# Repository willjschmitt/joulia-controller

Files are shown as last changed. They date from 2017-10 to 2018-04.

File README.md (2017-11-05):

# joulia-controller
 

Controller for the electric brewing hardware.

## Quickstart
Install Raspbian on a fresh SD card, and boot your Raspberry Pi.

Enable SSH (optional), for installing remotely. Make sure the password for the
main account is changed to a secure password. Enable I2C and SPI.

Install Anaconda (Miniconda), using the default options (installing to
`/home/pi/miniconda`):
```
wget http://repo.continuum.io/miniconda/Miniconda3-latest-Linux-armv7l.sh
bash Miniconda3-latest-Linux-arm71.sh
```
Answer all questions posed.

Clone the source:
```git clone https://github.com/willjschmitt/joulia-controller.git```

Create a conda environment and install the dependencies:
```
cd joulia-controller
/home/pi/miniconda3/bin/conda create --name joulia-controller python=3
source /home/pi/miniconda3/bin/activate joulia-controller
pip install -r requirements.txt
```

Create a log directory for joulia and change the owner to pi:
```
sudo mkdir /var/log/joulia
sudo chown pi:pi /var/log/joulia
```

### Automatic Startup
To automatically, launch the software on startup, install the contents from
`crontab` into the root cron table using:
```
sudo crontab -e
```

In the crontab, you must update the environment variables in angle brackets per
the definitions:
 * `JOULIA_WEBSERVER_HOST` - The webserver this controller should stream data to
   (usually `joulia.io`)
 * `JOULIA_WEBSERVER_AUTHTOKEN` - The authtoken provided in your dashboard on
   joulia.io, used to authenticate the controller and identify controller
   information.

### Manual Startup
Run the controller:
```
cd joulia-controller
source /home/pi/miniconda3/bin/activate joulia-controller
export JOULIA_WEBSERVER_HOST=joulia.io
export JOULIA_WEBSERVER_AUTHTOKEN=<insert token>
python main.py
```

## Connections to Hardware
This project is meant to be run on a Raspberry Pi and makes use of the GPIO pins.

### Analog Measurement
Make sure I2C is appropriately turned on on the Raspberry Pi. Install the Arduino I2C Analog Reader software onto the Arduino, so it can communicate the temperature measurements to the Raspberry Pi.

### Digital Control
Connect the Solid State Relay input gate for the Boil Kettle to Pin 0 on the Raspberry Pi.
Connect the Solid State Relay input gate for the Main Pump to Pin 1 on the Raspberry Pi.

## Related Projects
This project is part of the series of projects for the Joulia Brewing System:
* [joulia-webserver](https://github.com/willjschmitt/joulia-webserver) - Remote webserver to log data and allow for livestreaming of data to other clients and receive commands from other clients.
* [joulia-controller](https://github.com/willjschmitt/joula-controller) - This project.
* joulia-fermentation - Planned project to control the fementation operations.

## Licensing
Copyright 2016 William Schmitt. All Rights Reserved.

The intention is to make this project open-sourced, but at this moment is maintained under personal copyright until a few things can be worked through.

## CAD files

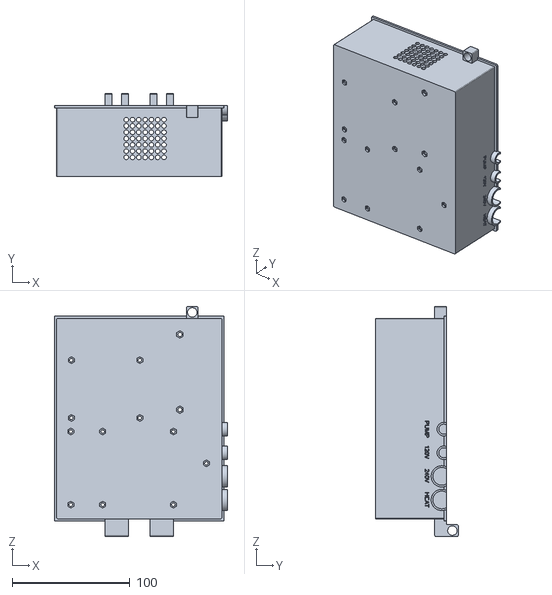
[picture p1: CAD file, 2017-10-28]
hardware/enclosure.stl
147.0 x 70.0 x 195.0

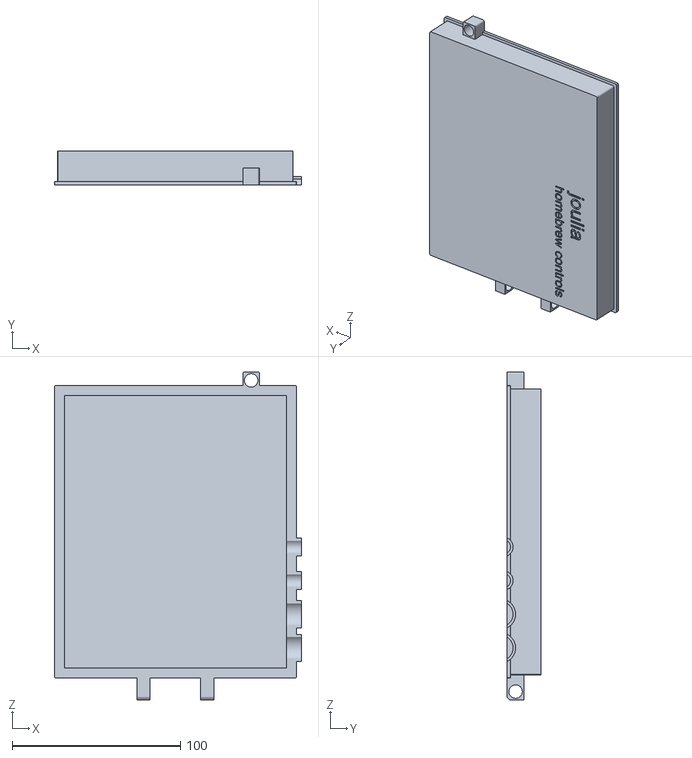
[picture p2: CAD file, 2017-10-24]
hardware/enclosure_lid.stl
147.0 x 20.0 x 195.0

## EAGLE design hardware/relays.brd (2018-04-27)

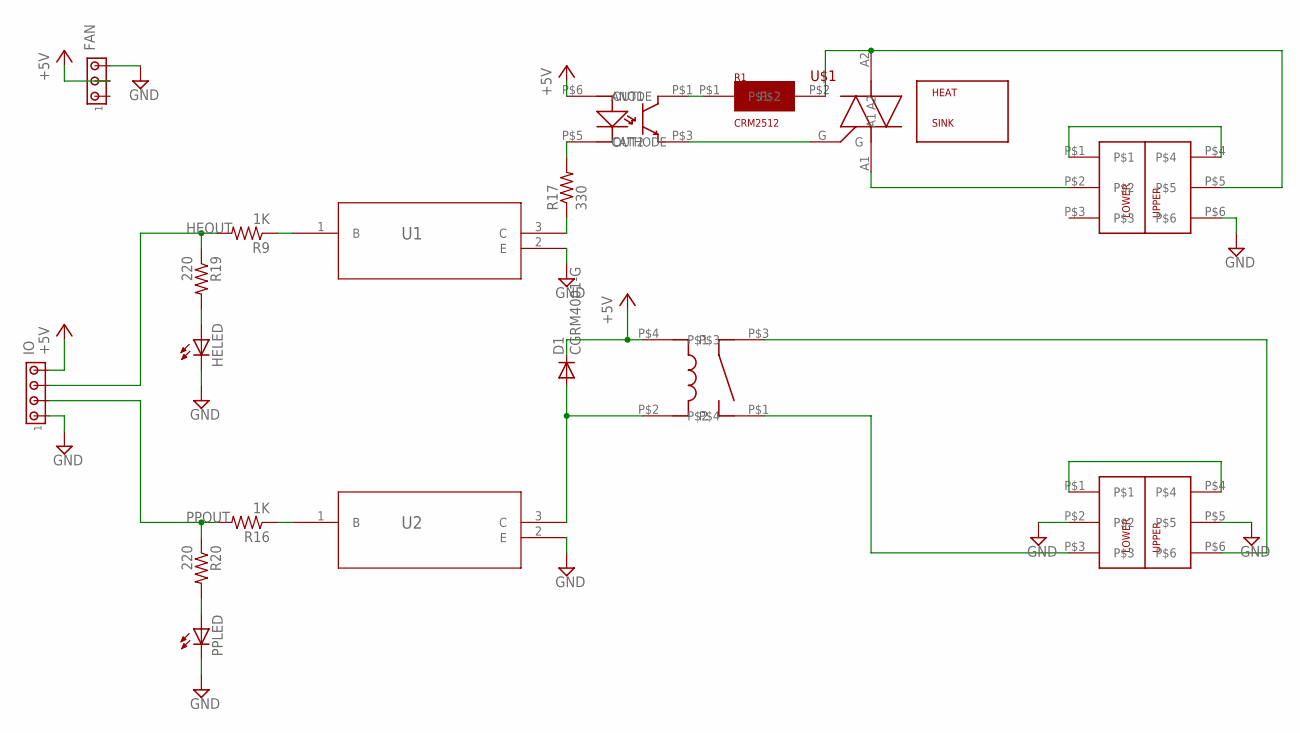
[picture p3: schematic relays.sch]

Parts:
D1: CGRM4001-G; SOD-123_MINI-SMA
FAN: MTA03-100; 10X03MTA
HELED: LED_ESML0603; LED_SML0603
IO: MTA04-100; 10X04MTA
PPLED: LED_ESML0603; LED_SML0603
R1: CRM2512; 2512(6432METRIC)
R9, R16: 1K; R0402
R17: 330; R1206
R19, R20: 220; R0402
U1, U2: MMBT2222ALT1G; SOT-23
U$1: T3050H-6I; TO-220
U$2: VM1-038-1AEHORIZONTAL; VM2-038-1AE
U$3: G5LE-1A4_DC5
U$4: PC1725041; PC-MKKDS1.5/3-5.08
U$5: MOC3020S; 6-SMD
U$6: PC1719028; PC-MKKDS5/3-9.5

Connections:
120H: U$3.P$1, U$4.P$3
120N: U$4.P$1, U$4.P$4
+5V: D1.C, FAN.2, IO.4, U$3.P$4, U$5.P$6 (ANODE)
+120: U$6.P$1, U$6.P$4
-120: U$1.A1, U$6.P$2
GND: FAN.3, HELED.C, IO.1, PPLED.C, U1.2 (E), U2.2 (E), U$4.P$2, U$4.P$5, U$6.P$6
HEOUT: IO.3, R9.2, R19.1
unnamed: R17.1, U1.3 (C)
unnamed: R17.2, U$5.P$5 (CATHODE)
unnamed: R9.1, U1.1 (B)
unnamed: R16.1, U2.1 (B)
unnamed: D1.A, U2.3 (C), U$3.P$2
unnamed: U$1.G, U$5.P$3 (OUT2)
unnamed: R1.P$1, U$5.P$1 (OUT1)
unnamed: R1.P$2, U$1.A2, U$6.P$5
unnamed: U$3.P$3, U$4.P$6
unnamed: HELED.A, R19.2
unnamed: PPLED.A, R20.2
PPOUT: IO.2, R16.2, R20.1

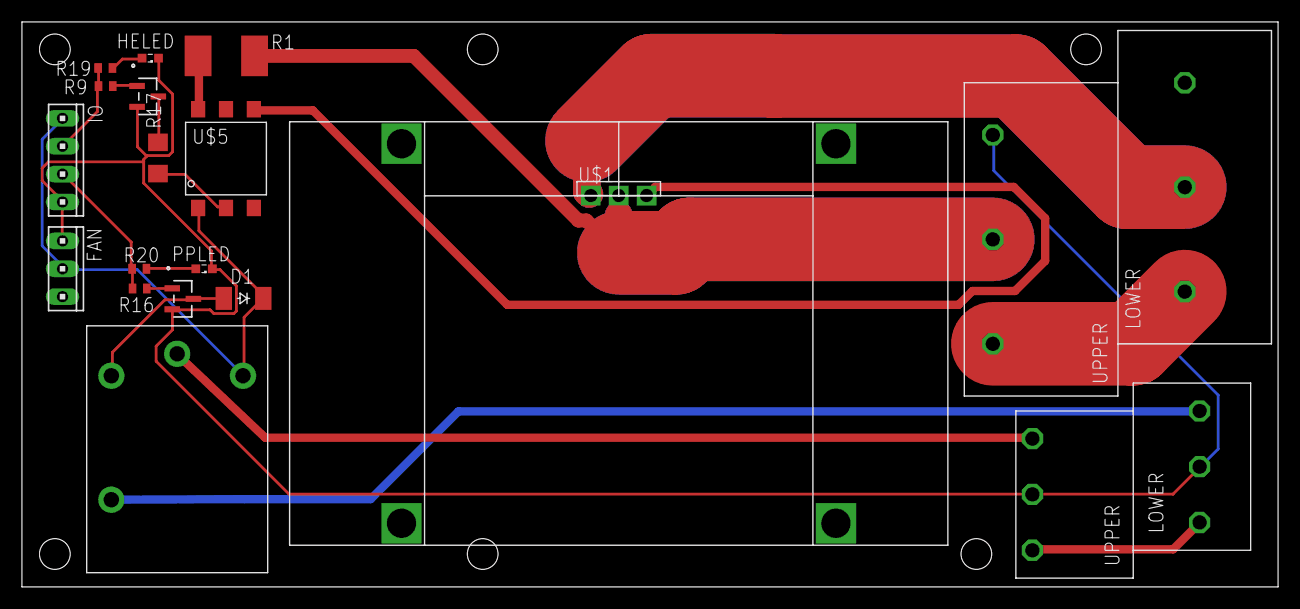
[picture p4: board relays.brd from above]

Board: 2 copper layers, 114.5 x 51.5 mm, 19 parts (0 on the bottom side), 19 nets.

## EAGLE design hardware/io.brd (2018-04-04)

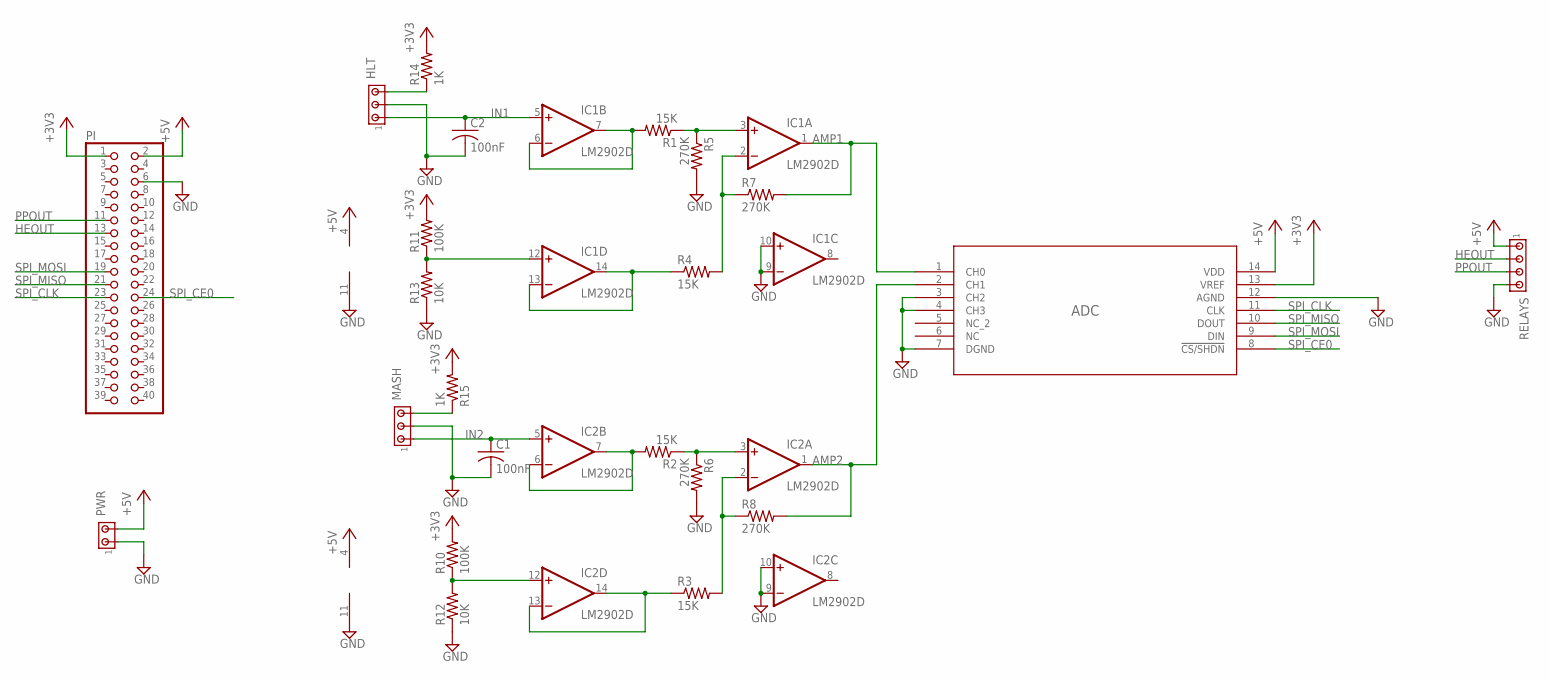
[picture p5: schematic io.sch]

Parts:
ADC: MCP3004-I/SL; SOIC14-N_MC
C1, C2: 100nF; C0402
HLT: MTA03-100; 10X03MTA
IC1, IC2: LM2902D; SO14
MASH: MTA03-100; 10X03MTA
PI: PINHD-2X20; 2X20
PWR: MTA02-100; 10X02MTA
R1, R2, R3, R4: 15K; R0402
R5, R6, R7, R8: 270K; R0402
R10, R11: 100K; R0402
R12, R13: 10K; R0402
R14, R15: 1K; R0402
RELAYS: MTA04-100; 10X04MTA

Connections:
+3V3: ADC.13 (VREF), PI.1, R10.2, R11.2, R14.2, R15.2
+5V: ADC.14 (VDD), IC1.4 (V+), IC2.4 (V+), PI.2, PWR.2, RELAYS.1
AMP1: ADC.1 (CH0), IC1.1 (OUT), R7.2
AMP2: ADC.2 (CH1), IC2.1 (OUT), R8.2
GND: ADC.3 (CH2), ADC.4 (CH3), ADC.7 (DGND), ADC.12 (AGND), C1.2, C2.2, HLT.2, IC1.9 (-IN), IC1.10 (+IN), IC1.11 (V-), IC2.9 (-IN), IC2.10 (+IN), IC2.11 (V-), MASH.2, PI.6, R5.2, R6.2, R12.1, R13.1, RELAYS.4
HEOUT: PI.13, RELAYS.2
IN1: C2.1, HLT.1, IC1.5 (+IN)
IN2: C1.1, IC2.5 (+IN), MASH.1
unnamed: IC1.6 (-IN), IC1.7 (OUT), R1.2
unnamed: IC1.3 (+IN), R1.1, R5.1
unnamed: IC1.12 (+IN), R11.1, R13.2
unnamed: IC1.2 (-IN), R4.2, R7.1
unnamed: IC1.13 (-IN), IC1.14 (OUT), R4.1
unnamed: IC2.6 (-IN), IC2.7 (OUT), R2.2
unnamed: IC2.3 (+IN), R2.1, R6.1
unnamed: IC2.2 (-IN), R3.2, R8.1
unnamed: IC2.12 (+IN), R10.1, R12.2
unnamed: IC2.13 (-IN), IC2.14 (OUT), R3.1
unnamed: MASH.3, R15.1
unnamed: HLT.3, R14.1
PPOUT: PI.11, RELAYS.3
SPI_CE0: ADC.8 (!CS/SHDN), PI.24
SPI_CLK: ADC.11 (CLK), PI.23
SPI_MISO: ADC.10 (DOUT), PI.21
SPI_MOSI: ADC.9 (DIN), PI.19

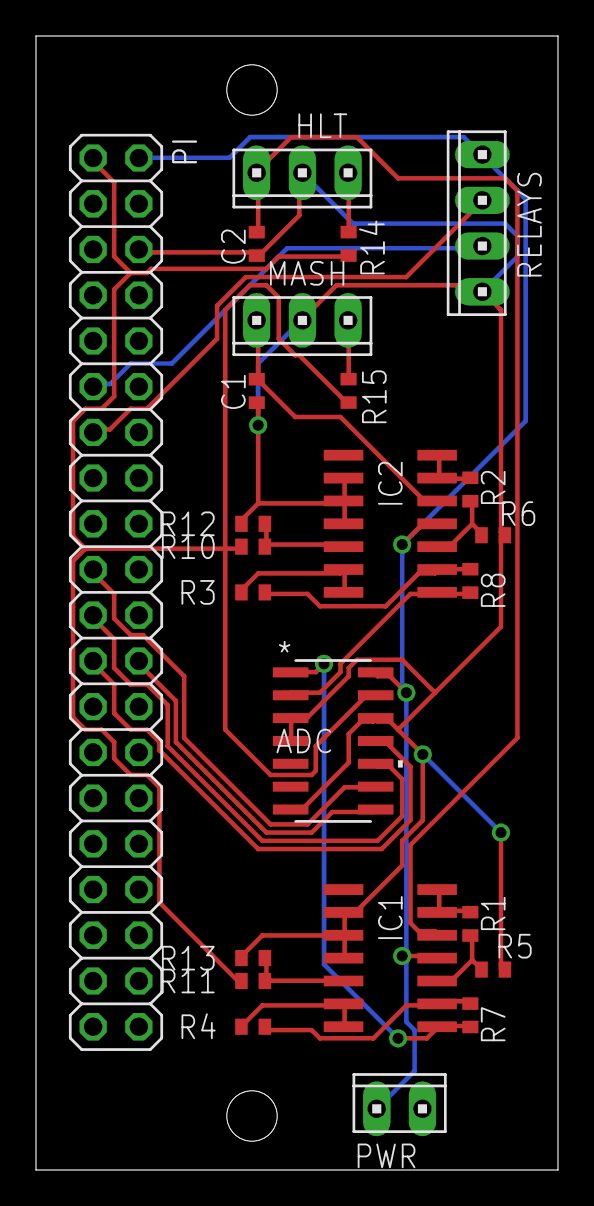
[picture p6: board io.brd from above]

Board: 2 copper layers, 29.0 x 63.0 mm, 24 parts (0 on the bottom side), 25 nets.

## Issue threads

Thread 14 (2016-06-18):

Split the i2c analog reader for the arduino into a new repository

willjschmitt, 2016-06-18:
The I2C analog reader is deployed on a totally separate device. It shouldn't be on the controller repository. The controller communicates with this code hosted elsewhere.

Closed 2017-05-22.

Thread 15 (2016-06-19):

Add dynamic detection of sensor_names.

willjschmitt, 2016-06-19:
Right now variable sensor names are hard coded into the classes rather than passed in or dynamically sensed. This works in the case where we really only have one of each item, but isn't sustainable.

Example:

```
class heatedVessel(temperatureMonitoredVessel):
    temperatureSetPoint = streaming_variable('boilKettle__temperatureSetPoint')
```

Not every `heatedVessel` will end up being the `boilKettle`, so we need to be able to dynamically change this on the fly.

willjschmitt, 2017-05-22:
I don't think this makes sense. We should instead provide settable ways to determine the name of the variable.

Closed 2017-05-22.

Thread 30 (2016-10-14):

Add i2c communication with sensors.

willjschmitt, 2016-10-14:

willjschmitt, 2016-10-23:
Solved by #31

Closed 2016-10-23.

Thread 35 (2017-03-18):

HeatedVessel gains should be calculated dynamically.

willjschmitt, 2017-03-18:
Gains are hard coded right now for the heated vessel regulator, but they should be calculated based off of the vessel rating and volume.

willjschmitt, 2017-03-18:
Already exists.

Closed 2017-03-18.

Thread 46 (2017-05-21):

Add support for MCP3004 ADC chip

willjschmitt, 2017-05-21:
Software only supports Arduino I2C ADC. New hardware boards use MCP3004 for ADC. Need to support communication with them.

Closed 2017-05-22.

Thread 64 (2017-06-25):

Fault tolerance against dropped i2c messages

willjschmitt, 2017-06-25:
i2c for the analog readers will get <0 values likely if the measurement failed. We should handle this exception unless the reader continuously fails

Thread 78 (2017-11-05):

Heating element should not be on during strike

willjschmitt, 2017-11-05:

willjschmitt, 2017-11-08:
Solved by #80

Closed 2017-11-08.

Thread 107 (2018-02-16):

Boil temperature measurement seems to be pretty noisy and stirring corrects it quite a bit

willjschmitt, 2018-02-16:
Maybe we need recirculation

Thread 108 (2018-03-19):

Allow recipe changes on the fly.

willjschmitt, 2018-03-19:
Occasionally it can be noticed the recipe was wrong, but only during the brew session. If a recipe change it made, maybe it should update the current session.

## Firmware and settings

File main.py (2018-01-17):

"""Main code for launching a Brewhouse joulia-controller."""
import logging.config
import os
import time

from Adafruit_GPIO.SPI import SpiDev
from Adafruit_MCP3008 import MCP3008
import RPi.GPIO as gpio
from tornado import ioloop

from brewery.system import System
from measurement.analog_reader import MCP3004AnalogReader
import settings

logging.config.dictConfig(settings.LOGGING_CONFIG)
LOGGER = logging.getLogger(__name__)


def main():
    """Main routine is for running as standalone controller on embedded
    hardware. Loads settings from module and env vars, and launches a
    controller instance."""
    root_directory = os.path.dirname(os.path.realpath(__file__))
    LOGGER.info('Changing working directory to the directory of this file: %s',
                root_directory)
    os.chdir(root_directory)

    analog_reader = create_analog_reader()
    gpio.setmode(gpio.BCM)

    system = System.create_from_settings(analog_reader, gpio)
    system.watch_for_start()
    ioloop.IOLoop.instance().start()


def create_analog_reader():
    spi_port = 0
    spi_device = 0
    spi = SpiDev(spi_port, spi_device)
    mcp = MCP3008(spi=spi)
    analog_reference_volts = 3.3
    return MCP3004AnalogReader(mcp, analog_reference_volts)


if __name__ == "__main__":
    # TODO(willjschmitt): This is a hack because networking is not up when this
    # is first called. We simply delay startup by 10seconds to allow networking
    # to come up.
    time.sleep(10.0)
    try:
        main()  # pragma: no cover
    except Exception as e:
        LOGGER.exception(e)
        raise e

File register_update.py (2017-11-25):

"""When run, posts to the joulia-webserver with an updated release.

Sends a POST to JOULIA_ENDPOINT with request details to be distributed to the
joulia-controllers to update to.
"""

import os
import requests

from brewery.brewhouse import Brewhouse


class Updater(object):
    """An updater to send controller update details to the Joulia webserver.

    Attributes:
        auth_token: The authentication token associate with the
            continuous_integration group on joulia-webserver.
        joulia_host: The host name with protocol prefix to send requests to.
    """
    RELEASE_ENDPOINT = '/brewery/api/joulia_controller_release/'
    STATE_ENDPOINT = '/brewery/api/brewing_state/'

    def __init__(self, auth_token, joulia_host):
        self.auth_token = auth_token
        self.joulia_host = joulia_host

    @property
    def _authentication_headers(self):
        return {'Authorization': 'Token {}'.format(self.auth_token)}

    def register_update(self, commit_hash):
        """Sends POST to joulia-webserver to indicate new release is available.

        Should be called as a deployment step for the master branch as determined by
        the .travis.yml.

        Args:
            commit_hash: The git commit hash to use for the new version.

        Returns:
            The primary key of the newly created update.
        """
        data = {'commit_hash': commit_hash}
        response = requests.post(
            '{}{}'.format(self.joulia_host, self.RELEASE_ENDPOINT), data=data,
            headers=self._authentication_headers)
        response.raise_for_status()
        return response.json()['id']

    def register_states(self, software_release_pk):
        """Sends all of the new states to the STATE_ENDPOINT.

        Provides joulia-webserver with the latest definitions of the controller
        states for the new software release, which can be used by web browsers,
        etc.

        Args:
            software_release_pk: The primary key for the new update registered
                with register_update.
        """
        for i, state in enumerate(Brewhouse.state_classes()):
            data = {
                'software_release': software_release_pk,
                'index': i,
                'name': state.NAME,
                'description': state.DESCRIPTION,
            }
            response = requests.post(
                '{}{}'.format(self.joulia_host, self.STATE_ENDPOINT),
                data=data,
                headers=self._authentication_headers)
            response.raise_for_status()


if __name__ == '__main__':
    updater = Updater(auth_token=os.environ['JOULIA_AUTH_TOKEN'],
                      joulia_host = os.environ['JOULIA_HOST'])
    software_release_pk = updater.register_update(
        commit_hash=os.environ['TRAVIS_COMMIT'])
    updater.register_states(software_release_pk)

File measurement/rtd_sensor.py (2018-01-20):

"""RTD Sensor module for resistance temperature devices"""

import logging
import time

from dsp.dsp import FirstOrderLag
from measurement.circuits import VariableResistanceVoltageDivider
from measurement.circuits import VoltageDivider
from measurement.op_amp import DifferentialAmplifier
from measurement.op_amp import VoltageFollower


LOGGER = logging.getLogger(__name__)


class RtdSensor(object):
    """A resistance temperature device that measures temperature by
    a measuring the voltage across the RTD in a voltage divider circuit,
    which is then amplified into an analog to digital converter (ADC) chip.

    Obtains the analog voltage measurement from an Arduino device connected
    on the I2C bus, with the amplifier circuit output connected to
    ``analog_in_pin``.

    See also: https://en.wikipedia.org/wiki/Resistance_thermometer

    Amplifier circuit roughly follows concept found at
    https://openenergymonitor.org/emon/buildingblocks/rtd-temperature-sensing,
    which includes three Op-Amp circuits: one following the RTD voltage,
    one following a voltage divider to give a reference voltage, and then
    calculating the difference between these voltages with a gain. This
    serves to optimize the resolution of the voltage measurement over the
    useful, realistic range for measuring voltage.

    Attributes:
        analog_reader: The AnalogReader object used for requesting analog
            measurements from.
        analog_in_pin: The analog in pin on the arduino pin, where the
            voltage measurement should be made from the RTD amplifier circuit
        alpha: The temperature coefficient of the RTD (Ohm/(Ohm*degC)).
            alpha is defined as (resistance @ 100degC- resistance @ 0degC)
            / (100 * resistance @ 100degC)
        zero_resistance: The resistance of the tem
        analog_reference_voltage: Reference voltage for the ADC
            measurement as set on the Arduino.
        scale: Multiplier on the measured temperature (degF/degF) for
            calibration.
        offset: Linear shift/offset on the measured temperature
            (in degF) for calibration
        tau: First order low pass filter time constant to remove high
            frequency noise from circuit measurement
        amplifier: The differential amplifier amplifying the measured voltage.
        offset_follower: The voltage follower for voltage offset.
        offset_divider: The voltage divider generating the voltage offset.
        rtd_follower: The voltage follower for the rtd input.
        rtd_divider: The voltage divider generating a signal voltage from the
            RTD.
        temperature_unfiltered: The unfiltered raw temperature measured from
            the RTD.
    """

    def __init__(self, analog_reader, analog_pin, alpha, zero_resistance,
                 analog_reference_voltage, tau, vcc, resistance_rtd_top,
                 amplifier_resistance_a, amplifier_resistance_b,
                 offset_resistance_bottom, offset_resistance_top, scale=1.0,
                 offset=0.0):
        """Constructor

        Args:
            vcc: The voltage input to the amplifier circuit, used for
                reference, from the Arduino (Volts)
            amplifier_resistance_a: The resistance that serves as the
                denominator in the gain of the difference amplifier (Ohms)
            amplifier_resistance_b: The resistance that serves as the
                numerator in the gain of the difference amplifier (Ohms)
            offset_resistance_bottom: The resistance in the bottom of the
                voltage divider for the offset voltage follower circuit (Ohms)
            offset_resistance_top: The resistance in the top of the
                voltage divider for the offset voltage follower circuit (Ohms)
        """
        self.analog_reader = analog_reader

        self.temperature_filter = FirstOrderLag(time, tau)

        self.analog_in_pin = analog_pin
        self.analog_reference_voltage = analog_reference_voltage

        self.alpha = alpha
        self.zero_resistance = zero_resistance

        self.scale = scale
        self.offset = offset

        self.amplifier = DifferentialAmplifier(
            amplifier_resistance_a, amplifier_resistance_b)

        self.offset_follower = VoltageFollower()
        self.offset_divider = VoltageDivider(
            offset_resistance_top, offset_resistance_bottom)

        self.rtd_follower = VoltageFollower()
        self.rtd_divider = VariableResistanceVoltageDivider(
            resistance_rtd_top, vcc)

        self.vcc = vcc

        self.temperature_unfiltered = 0.0

    @classmethod
    def from_json(cls, analog_reader, configuration):
        """Factory for creating a RtdSensor from JSON configuration."""
        analog_pin = configuration["analog_pin"]
        alpha = configuration["rtd"]["alpha"]
        zero_resistance = configuration["rtd"]["zero_resistance"]
        analog_reference_voltage = configuration["analog_reference"]
        tau = configuration["tau_filter"]
        vcc = configuration["amplifier"]["vcc"]
        resistance_rtd_top = configuration["amplifier"]["rtd_top_resistance"]
        amplifier_resistance_a \
            = configuration["amplifier"]["amplifier_resistance_a"]
        amplifier_resistance_b \
            = configuration["amplifier"]["amplifier_resistance_b"]
        offset_resistance_bottom \
            = configuration["amplifier"]["offset_resistance_bottom"]
        offset_resistance_top \
            = configuration["amplifier"]["offset_resistance_top"]
        return cls(analog_reader, analog_pin, alpha, zero_resistance,
                   analog_reference_voltage, tau, vcc, resistance_rtd_top,
                   amplifier_resistance_a, amplifier_resistance_b,
                   offset_resistance_bottom, offset_resistance_top)

    @property
    def temperature(self):
        """Filtered temperature measured from the RTD amplifier circuit."""
        return self.temperature_filter.filtered

    def measure(self):
        """Samples the voltage from the RTD amplifier circuit and calculates
        the temperature. Applies the filter calculation to newly sampled
        temperature.
        """
        voltage_measured = self.analog_reader.read_voltage(self.analog_in_pin)

        # Back out the voltage at the RTD based on the amplifier circuit
        voltage_rtd = (-self.amplifier.v_in(voltage_measured)
                       + self.offset_divider.v_out(self.vcc))

        resistance_rtd = self.rtd_divider.resistance_bottom(voltage_rtd)

        temperature = self._resistance_to_temperature(resistance_rtd)

        # Add calibration scaling and offset
        temperature_calibrated = (temperature * self.scale) + self.offset

        self.temperature_unfiltered = temperature_calibrated
        self.temperature_filter.filter(temperature_calibrated)
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

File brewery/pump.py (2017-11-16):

"""This module models and interacts with pump objects for pumping liquids.
"""

import logging

from measurement.gpio import OutputPin
from variables import OverridableVariable
from variables import SubscribableVariable

LOGGER = logging.getLogger(__name__)


class SimplePump(object):
    """A simple on/off pump.

    Attributes:
        pump_status: Boolean indicating the pump is being powered.
        pin: The gpio output pin number controlling the pump power.
    """

    emergency_stop = SubscribableVariable('emergency_stop', default=False)
    pump_status = OverridableVariable('main_pump__pump_status', default=False)

    def __init__(self, client, recipe_instance, pin):
        self._register(client, recipe_instance)
        self.enabled = False
        self.pin = pin

    @classmethod
    def from_json(cls, client, gpio, recipe_instance, configuration):
        """Factory for creating a SimplePump from JSON configuration."""
        pin = OutputPin(gpio, configuration["pin"])
        return cls(client, recipe_instance, pin)

    def _register(self, client, recipe_instance):
        """Registers this instance with the properties by submitting the
        ``recipe_instance`` to them.

        Args:
            client: The websocket client used for communicated with the server.
            recipe_instance: The id for the recipe instance we are
                connecting with
        """
        SimplePump.emergency_stop.register(client, self, recipe_instance)
        SimplePump.pump_status.register(client, self, recipe_instance)

    def turn_off(self):
        """Turns pump off."""
        self.pump_status = False
        self.pin.set_off()

    def turn_on(self):
        """Turns pump on."""
        if self.emergency_stop:
            LOGGER.info('Emergency stop engaged. Redirecting to turn_off call.')
            self.turn_off()
            return
        self.pump_status = True
        self.pin.set_on()

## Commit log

2016-06-19 Switched subscribable and overridable variables to be descriptors, which makes their use much cleaner and simpler.
2016-06-19 Fixed the utility variable subscription.
    [utils.py, vessels.py]
2016-06-19 Fixed support for setting overrides.
    [utils.py, vessels.py]
2016-06-19 Added streamable variable implemented as a descriptor. Implemented timer to start.
    Need to keep datastreamer for the @property style variables.
2016-06-20 Temperature setpoint variables changes to overridable variables.
2016-06-22 Moved sensor grab into the try to call.
2016-07-03 Brewery waits for the server to say it should be active and stops running controls when the server says it is no longer active.
    [main.py, settings.py]
2016-07-03 Add temperature setpoints for items when offline that equal the current temps.
2016-08-23 Removing old c code, which originated from arduino code.
2016-09-13 Lots of style fixes and refactoring.
    [brewhouse.py, main.py, utils.py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]
2016-09-13 Cleaning up pump module.
2016-09-17 Added decorators to check if an instance is registered or subscribed already.
    Many style fixes.
    [utils.py]
2016-09-17 Fixed several bugs from the refactoring in the variable layout.
    [brewhouse.py, settings.py, utils.py]
2016-09-17 Changing python to be the hypriot Python docker image, so it runs on ARM (RPi).
2016-09-18 Make sure we setup pinmode for GPIO, which crust doesn't do?
    [vessels.py]
2016-10-14 RTD sensor communicates via i2c.
2016-10-14 Changing i2c bus.
2016-10-14 Adding i2c installs to docker file.
2016-10-15 Fixed API call to smbus.
    [brewhouse.py, main.py, settings.py]
2017-03-07 Adding main board design.
    Adds a board connecting Raspberry Pi to ADC chip and amplifer circuits for RTD sensors. Transistor buffers for SSRs. Convenient plugs for power, SSRs, and RTDs.
    [joulia_controller.brd, joulia_controller.sch]
2017-03-10 Fixed tests and 100% coverage on ManagedVariable
    [variables_test.py]
2017-03-14 Added op_amp module for helping with op_amp circuits.
2017-03-14 Added helpers for calculating circuits.
2017-03-18 Coverage for Regulator.
2017-03-18 Abstracting gpio and coverage for pumps.
2017-03-18 Coverage for SimpleVessel and TemperatureMonitoredVessel.
2017-03-18 Tests for HeatedVessel.
2017-03-19 Refactored temperature rate calculation into utils.
2017-03-19 Caught missed line in vessels.
    [vessels_test.py]
2017-03-19 Removing unnecessary lines and adding pragma: no-cover comments for lines that are intentionally avoiding to be hit.
    [joulia_webserver_client_test.py, variables_test.py]
2017-03-21 Fixing RtdSensor to use AnalogReader.
    [rtd_sensor.py, rtd_sensor_test.py]
2017-03-21 Fixed webserver logging statement.
    [joulia_webserver_client.py]
2017-03-21 Fixes and tests a good deal of brewhouse.
    [brewhouse.py, brewhouse_test.py]
2017-03-21 Adding RuntimeError to error check for import hack.
    [main.py]
2017-04-30 Pump and heating element have emergency stop monitoring now.
2017-04-30 Adding e-stop to HeatExchangedVessel.
2017-05-21 Refactoring voltage conversion into analog measurement interface.
2017-05-22 Handling case to create MCP3008 when testing.
2017-05-22 Removing i2c arduino code, which has been moved to a new repo.
    This method is being deprecated for analog measurement anyways.
2017-05-29 Duty cycle for brewing vessel correctly turns on/off heating element.
    Refactored names for turn_off/on into disable/enable when their meaning was doubled.
    [brewhouse.py, brewhouse_test.py, vessels.py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]
2017-05-29 Fixing websocket address, which did not include ws endpoint.
    [main.py]
2017-06-06 Fix recipe_instance from start watching.
    [main.py]
2017-06-06 Websocket is correctly returned.
    [joulia_webserver_client.py]
2017-06-07 Fix sensor name for subscribing variable identification.
    [variables.py]
2017-06-07 Only accept callback for current subscriber.
2017-06-09 Fixed RTD alpha values and RTD init order.
    [main.py]
2017-06-12 Fixing tests for start/stop.
    [main_test.py, stub_async_http_client.py]
2017-06-13 Adding FileNotFoundError as exception handling for Adafruit SPI library.
2017-06-21 Correcting test failures for state machine/brewhouse.
    [brewhouse.py]
2017-06-25 Correcting pin numbers for pump and heating element.
    [main.py]
2017-06-25 Increasing power trace width and adding input resistors to transistors.
    [joulia_controller.brd, joulia_controller.sch]
2017-07-25 Fixed checkout of new commits.
    [update.py, update_test.py]
2017-07-26 Create logging directory if it doesn't exist.
    [settings.py]
2017-07-26 Fallback to current directory for logging in Travis.
2017-07-26 Fix propagate variable in logging.
    [settings.py]
2017-07-26 Turn off update timer on reconnect.
    Ensures new timers are not spawned.
2017-07-27 Adding Triac and Heatsink
    Need opto-isolation and power terminals.
    [joulia_controller.brd, joulia_controller.sch]
2017-08-08 Adding connectors and SSR to board
    [joulia_controller.brd, joulia_controller.sch]
2017-08-08 Routing and rearrangement for power
    [joulia_controller.brd, joulia_controller.sch]
2017-08-08 Routing of smaller traces.
    [joulia_controller.brd]
2017-08-23 Fix optoisolator resistors and update power header
    [joulia_controller.brd, joulia_controller.sch]
2017-08-23 Adding first enclosure checkin
    [enclosure.stl]
2017-09-06 Improves board layout and autorouting
    [joulia_controller.brd, joulia_controller.sch]
2017-09-09 Using smaller resistor for optoisolator emitter.
    [joulia_controller.brd, joulia_controller.sch]
2017-09-09 Updating heat sink outline.
    [joulia_controller.brd, joulia_controller.sch]
2017-09-09 Complete wiring with HV circuit and rearrangement
    [joulia_controller.brd, joulia_controller.sch]
2017-09-09 Fix board size and hole placement.
    [joulia_controller.brd]
2017-09-09 Adjust plugs to be consistently spaced.
    [joulia_controller.brd, joulia_controller.sch]
2017-09-09 Rewiring pump to be consistent with HE.
    [joulia_controller.brd, joulia_controller.sch]
2017-09-10 First pass of enclosure.
    [enclosure.stl]
2017-09-20 Adds lid and and improves bottom.
    [enclosure.stl, enclosure_lid.stl]
2017-09-25 Correcting naming for amplifier resistors.
    [brewhouse_test.py, rtd_sensor.py, rtd_sensor_test.py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]
2017-10-17 Larger power and fan holes
    [enclosure.stl, enclosure_lid.stl]
2017-10-17 Thicker walls
    [enclosure.stl, enclosure_lid.stl]
2017-10-24 Correcting RTD holes.
    Also adjusts fan holes. Changes text to be recessed rather than appended.
    [enclosure.stl, enclosure_lid.stl]
2017-10-28 Increase nut hole size
    [enclosure.stl]
2017-10-28 Adding LEDs and Fan Connector
    [joulia_controller.brd, joulia_controller.sch]
2017-11-05 Correct HOST setting case in README
2017-11-16 Make pump status an overridable variable
2017-11-19 Posts current states for controller to webserver
2017-11-25 Refactors mash profile to fix bug
    [brewhouse.py, brewhouse_test.py, vessels.py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]
2017-11-26 Fixes pylint errors in brewery package
    [brewhouse.py, brewhouse_test.py, pump_test.py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]
2017-11-26 Fixes pylint errors in dsp package
    [brewhouse.py]
2017-11-26 Fixes pylint errors for measurement package.
    [analog_reader_test.py, circuits_test.py, gpio.py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]
2017-11-26 Fixes pylint errors for testing package.
    [stub_analog_reader.py, stub_async_http_client.py, stub_gpio.py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]
2017-11-26 Refactors main code to support simulation
    No longer doing soft fallbacks onto stub code. Stub code must be started explicitly.
    [main_simulated.py, stub_mcp3008.py, system.py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]
2017-11-26 Adds reversal for temperature to rtd sensor.
    [rtd_sensor.py, rtd_sensor_test.py]
2017-11-30 Adds support for simulating temperatures.
2017-12-16 Print pylint version because of erroneous errors.
2018-01-14 Adding sensor id to subscribing message.
2018-01-15 Fixes in default variable type
    [variables.py]
2018-01-16 Correct the variable type source to fix test.
    [variables.py]
2018-01-16 Corrects update to be PUT instead of POST.
    [stub_requests.py]
2018-01-17 Startups are correct now.
    Simulations were not starting the simulator. Includes refactoring for start/end watch.
    [main.py, main_simulated.py, system.py]
2018-01-20 Temporary logging for back calculation of rtd voltage.
2018-01-20 Correct watching for end request.
    [system.py]
2018-03-19 Stops setting boil temp in mash state.
    Fixes #104
    [brewhouse.py, brewhouse_test.py]
2018-03-24 Switching to mechanical relay for pump and horizontal heatsink.
    [joulia_controller.brd, joulia_controller.sch]
2018-03-25 Removing extraneous resistor for relay.
    [joulia_controller.brd, joulia_controller.sch]
2018-03-25 Switches two plugs for one board terminal for 120V connections.
    [joulia_controller.brd, joulia_controller.sch]
2018-03-25 Switches two plugs for one board terminal for 240V connections.
    [joulia_controller.brd, joulia_controller.sch]
2018-03-25 Move ground to 120V connection.
    [joulia_controller.brd, joulia_controller.sch]
2018-03-25 Better relay layout.
    [joulia_controller.brd]
2018-03-26 Split relay into new board.
    [relays.brd, relays.sch]
2018-04-04 IO and Relay boards are distinct
    [io.brd, io.sch, relays.brd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]
2018-04-14 Fix relay holes, triac holes and orientation, and DRC issues.
    [relays.brd, relays.sch]

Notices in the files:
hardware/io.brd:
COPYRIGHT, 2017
